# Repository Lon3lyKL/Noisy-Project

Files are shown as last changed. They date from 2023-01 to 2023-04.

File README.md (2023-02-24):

# Noisy-Project
This is a project by SSTudents for SSTudent to tell them to keep quiet during O Level Practical ;-;

Resources:
Check Resouces file

DATA:
- https://docs.google.com/spreadsheets/d/1UvS9qfeL-FOSvyElGNO4R17XsOqtYgqw1WRZXdFCIbs/edit#gid=698862983 
- cleaned up and formated with graph

27/1/23: Things to do
"use 741" -ms teo for speech pricessing
Kar Lok:
-   add a dc voltage regulator that can supply >3A current
    - we can use this 5v5A one https://www.amazon.sg/Pololu-Step-Down-Voltage-Regulator-D24V50F5/dp/B01M659ER2 
-   make the Rtc + SD card work
    - sd card formatting should be [dd/mm/yy_hh.mm.ss_data]
-  change the mega to a mini(save space) / mega
-  redesigning the lights
    - mounting of the leds
    - diffuser
    - distance to diffuser
-  add a fan into the control box to provide cooling to the components cos it gna run for 24/7

Jay:
-   try to do mic v2 and make it work with a condensor mic

3/2/23: Update
- we integrated the sd card and rtc
- we set up the recording structure into the sd card
- we set up the rtc to the exact time
- we found a few osciliscopes dead
- we found a few broken osciliscope probe
- we made the amplifier circuit to work
    - the mic we used is the wrong one
            - the pickup pattern is completely wrong
    - we used the lm741 ic to amplify it

what we need to do: 
- get a better mic
- go back on wed to collect the data
- pcb hehehawhaw

8/2/23: Update
- the data on monday was ok with us being able to see the points where students came down for thier breaks and there was noise recorded
- the tuesday data was weird it got all flipped and we have no clue what happened
- first time collecting the data it was good
- the sd card and the rtc works
- the google sheet was created with the correct formuls to create the graph to visualise the data

22/2/23: Update
- we got the data from 8-10 feb and it was ok, sensitivity of the mic has to be changed
    - at soome poitns the mic recoded 22 whcih was loud(we still have no clue what happened)
- changed the sampling rate to every 30 seconds form every 10 seconds
- changed the parameters for when the light will trigger for the dfferent volumes
    - 900> == quiet
    - 600> <900 == modertely noisy
    - <600 == very noisy
- tested it with some of us talking and got it to moderate noise
- realised the rtc was configured to be one day ahead(small problem, the date wont be used)
- planning to leave it until 24 feb(fri) even overnicet to collect the data
- fine tuning the number to be able to record a video of it for the principal
- shoudl be the last time we touched the code, nothing else needs to be changed
- 30s allows more data to be averaged out with the anomolies measured from electrical noise to be removed
- it will change the light less often thus the students will not stand there to watch it
- the green light on top of the mic can be used to check if the calibration of the gain is corrected
- changed the name of the project to "Noisy Student Project" from "Noisy Boi Project" to use more gender neutral terms
- (maybe we changed it before today im not sure) but ms teo was made aware of it today
- heard from other students it works sometimes when they tried to use it

things done: 
- acrylic top pannel was created
- tuned the mic to the correct sensitivity

things to improve: 
- add proper connectors for the rgb
- test the mic amps: jay
- test the rf moduled: karlok
- redesign led case: karlok
- redesign led mounting system: karlok (jay has some comments about this)

24/2/23: Update
- 22-23 feb data was very good
- we are able to see when the students are making noise
- the students breaks and end of school times were clearly visiable in the graph
- changed the limit when quiet to 800
- changed the limit when abit noisy to 550 and 800
- changed the limit when very noisy 550
- sensor will be placed at corridor between canteen and science lab
- sound sensor to be placed in science lab to record and corelate data
- v2 will have design improvements
- this mic is probably good enough and we wont need to get a different long range mic
- there was an error in the google sheets
    - taking the last 3 numbers willl miss out the times when the number is at 1020 and take it as 20
    - making it show up as anamoly
- changed to take the last 4 numbers

things to improve: 
- see 22feb comments
- led wire needs strain relief
- v2 to be done by next fri(3 mar)
- create a noise recorder for sci lab(sensor+sdcard)
- generally clean it up

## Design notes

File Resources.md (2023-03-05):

Resources:
- https://arduino-tutorials.net/tutorial/drawing-sound-sensor-data-on-serial-plotter sound sensor
- https://www.circuitbasics.com/how-to-use-a-real-time-clock-module-with-the-arduino/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,and%20Time%20on%20an%20Arduino. rtc
- https://randomnerdtutorials.com/guide-for-microphone-sound-sensor-with-arduino/ sound sensor
- https://www.instructables.com/Arduino-Audio-Input/ arduino audio input
- https://circuitdigest.com/microcontroller-projects/interfacing-ds3231-rtc-with-arduino-and-diy-digital-clock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,hour%20or%2012%2Dhour%20mode. arduino rtc how to use
- https://forum.arduino.cc/t/zs-042-ds3231-rtc-module/268862 notes about the rtc charging circuit
- https://digitalab.org/2016/08/microphone-pre-amplifier-using-lm358/#.Y_Y89exBwdH lm358 audio preamp
- https://digitalab.org/2012/10/audio-amplifier-using-lm386/#.Y_Y89exBwdF lm386 audio amp
- https://www.digikey.sg/en/products/detail/texas-instruments/LM358P/277042 lm358 datasheet
- https://www.ti.com/lit/ds/symlink/lm358.pdf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 lm358 datasheet again
- https://www.whitenoisestudio.com/how-to/cable-soldering-schematics/ xlr mic wiring digram
- https://bestengineeringprojects.com/microphone-amplifier-using-op-amp-741/ lm741 preamp
- https://bestengineeringprojects.com/dynamic-microphone-pre-amplifier-circuit/ dynamic mic preamp without ic
- http://www.learningaboutelectronics.com/Articles/Difference-amplifier-circuit.php lm741 preamp(didnt work)
- http://www.learningaboutelectronics.com/Articles/How-to-connect-a-LM741-op-amp-chip-to-a-circuit lm741 amp(didnt work again)
- https://www.got-it.ai/solutions/excel-chat/excel-tutorial/miscellaneous/copy-value-from-every-nth-row copying from every nth row excel
- https://spreadsheetpoint.com/apply-formula-to-entire-column-google-sheets/ apply formula to entire column (Cmd+D)
- https://spreadsheetpoint.com/how-to-insert-multiple-columns-in-google-sheets/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,of%2026%20at%20a%20time.&text=This%20happens%20because%2C%20by%20default,Sheets%20only%20displays%2026%20columns. add more columns (Cmd+A then insert columns)
- https://www.google.com/search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 long range mic search
- https://sg.rs-online.com/web/p/industrial-circular-connectors/1115761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 3 pin connecter used for rgb and mic
- https://lastminuteengineers.com/ds3231-rtc-arduino-tutorial/ another rtc 
- https://jaazz.me/2014/03/11/how-to-wire-an-unbalanced-microphone-to-a-balanced-xlr-input/ xlr input
- https://www.terralec.co.uk/CableConnectors.aspx xlr input

Others:
- https://www.convert-measurement-units.com/conversion-calculator.php?type=kapazitaet  unit conversion calculator to save time LMAO
- https://www.google.com/search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 lm741 amps (google search)

each Led Package draws 50mA of curent at 5v https://www.pololu.com/product/2547
we have 100 leds which means 50mA*100=5000mA=5A
the voltage regulator on the mega is a D24V5F5, which outputs at 5v at a max of 500mA https://forum.arduino.cc/t/replace-voltage-regulator-on-arduino-mega/402325/4 

Arduino & C++ extension can be added to vscode to use to write arduino
arduino can be programmed through vscode and not need to use the arduino app
guide of how to use it https://www.youtube.com/watch?v=WVZxK2MEbE4

github notes: https://stackoverflow.com/questions/30038999/differences-between-commit-commit-and-push-commit-and-sync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,them%20with%20your%20local%20repository%20%22 
In GitHub, the "commit" action saves your changes to the local repository, while the "push" action sends those changes to a remote repository. "Commit and push" combines these two actions into one, allowing you to save your changes locally and then push them to a remote repository with a single command.

"Commit and sync" is a similar concept, but it also pulls down any changes from the remote repository that have been made since your last commit. This allows you to keep your local repository up to date with the latest changes from other contributors.

Finally, "commit and create pull request" combines the commit and push actions with the creation of a new pull request. This allows you to propose your changes for review by other contributors to the project, and start a discussion about the changes you've made.

In summary, the differences between these options are:

"Commit": saves your changes to the local repository "Commit and push": saves your changes to the local repository and pushes them to the remote repository "Commit and sync": saves your changes to the local repository, pulls down any new changes from the remote repository, and merges them with your local repository "Commit and create pull request": saves your changes to the local repository, pushes them to the remote repository, and creates a new pull request for review.
- https://www.pagerduty.com/resources/learn/what-is-a-pull-request/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,with%20the%20main%20project%20repository. what pull requests are (tell others you are done and need a review of code)

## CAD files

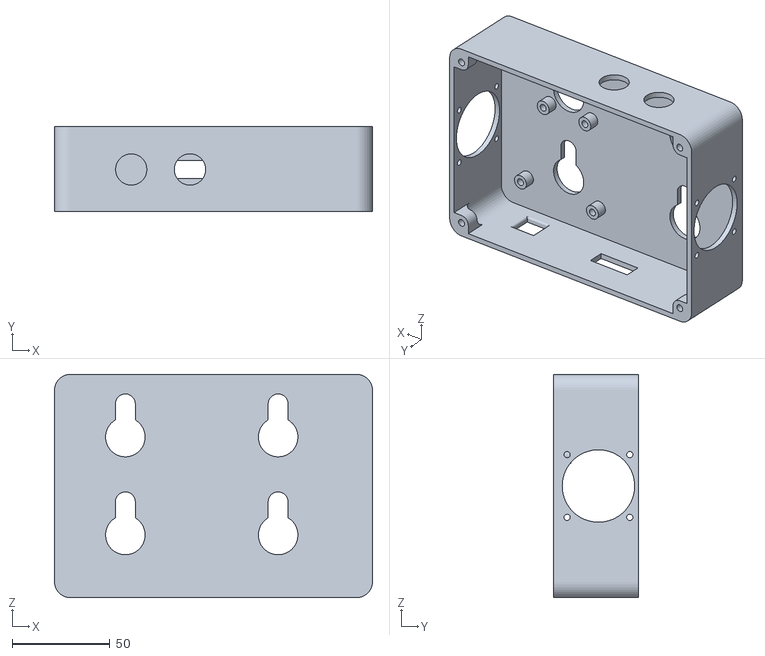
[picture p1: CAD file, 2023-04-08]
Noisy Project@SST/Contorl Box Model/Back Base V3.stl
162.3 x 43.5 x 114.0

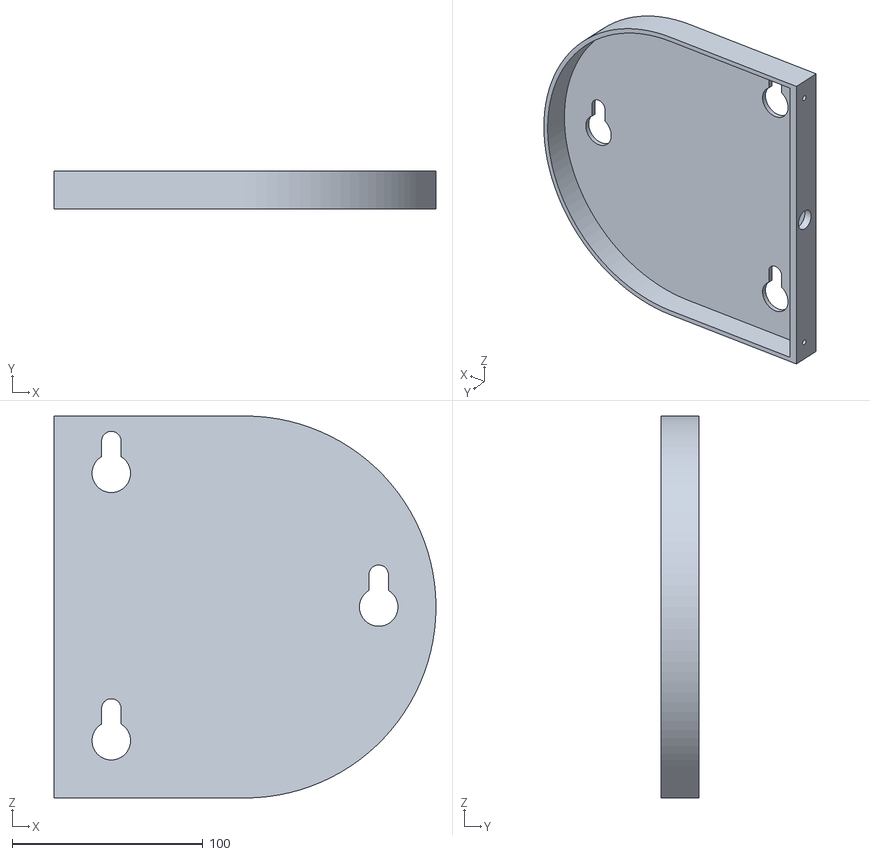
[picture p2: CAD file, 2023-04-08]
Noisy Project@SST/Light Model/Light Left.stl
200.0 x 20.0 x 200.0

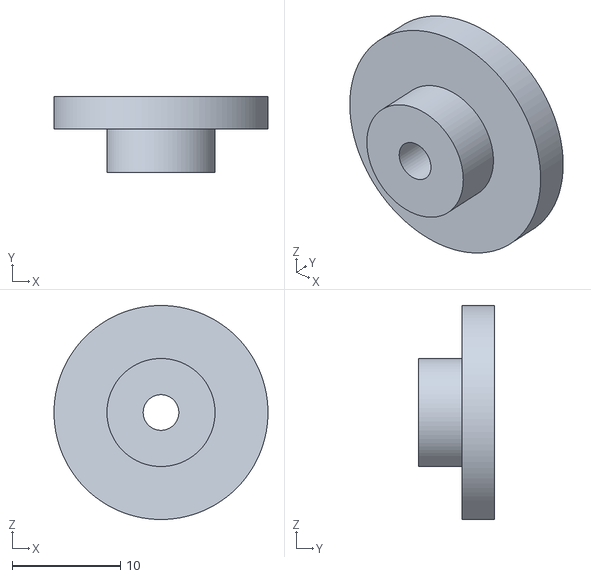
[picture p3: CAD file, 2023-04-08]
Noisy Project@SST/Mount.stl
19.8 x 7.00 x 19.8

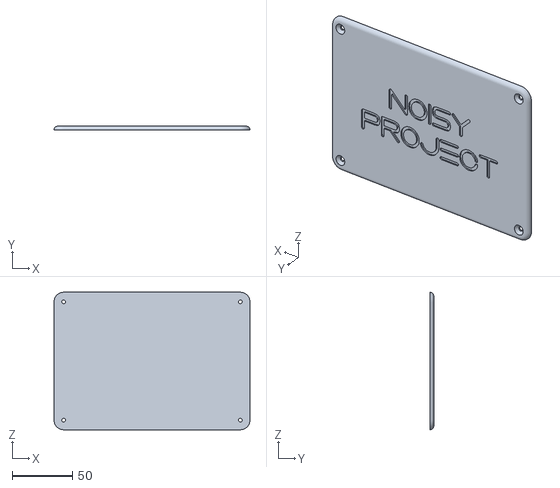
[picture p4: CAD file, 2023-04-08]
Noisy Project@SST/Contorl Box Model/Front Plate.stl
162.3 x 3.00 x 113.9

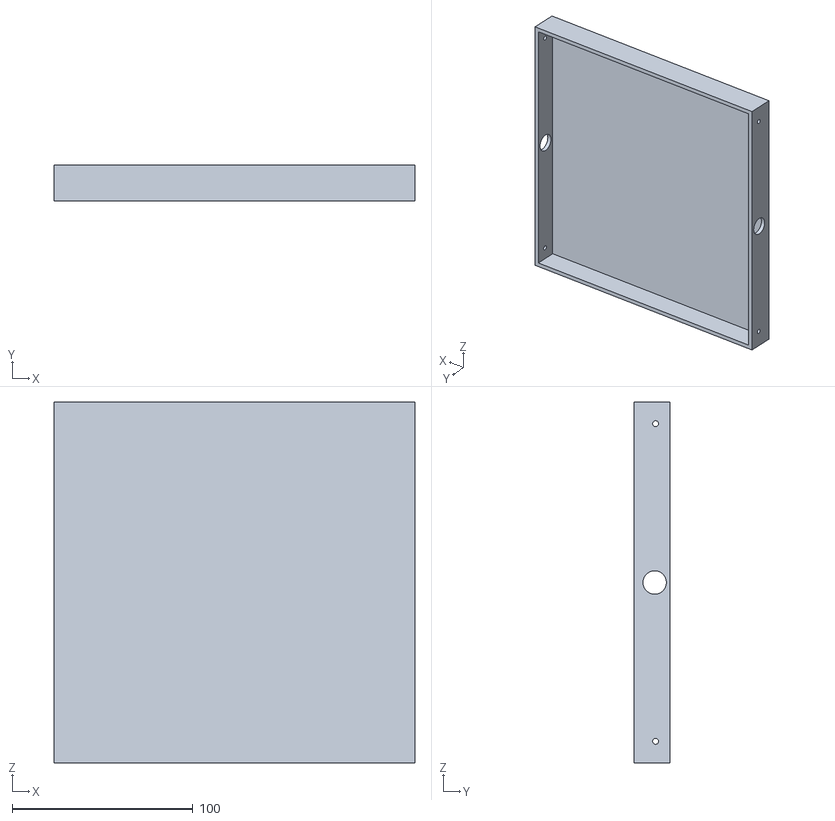
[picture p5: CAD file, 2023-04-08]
Noisy Project@SST/Light Model/Light Middle.stl
200.0 x 20.0 x 200.0

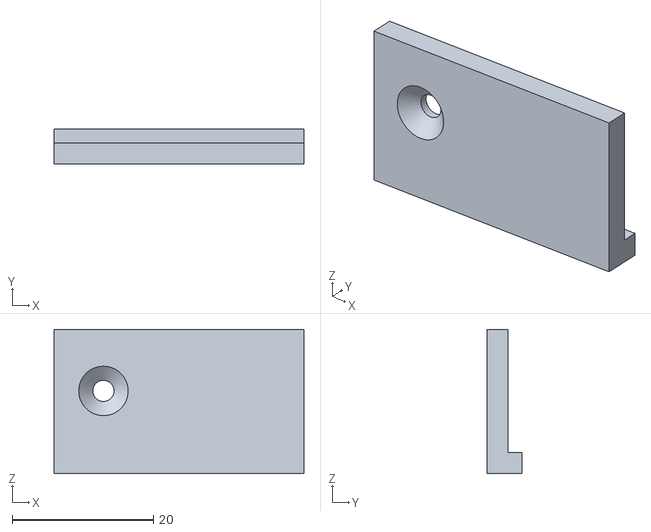
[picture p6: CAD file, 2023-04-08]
Noisy Project@SST/Mic Mount.stl
35.4 x 5.00 x 20.4

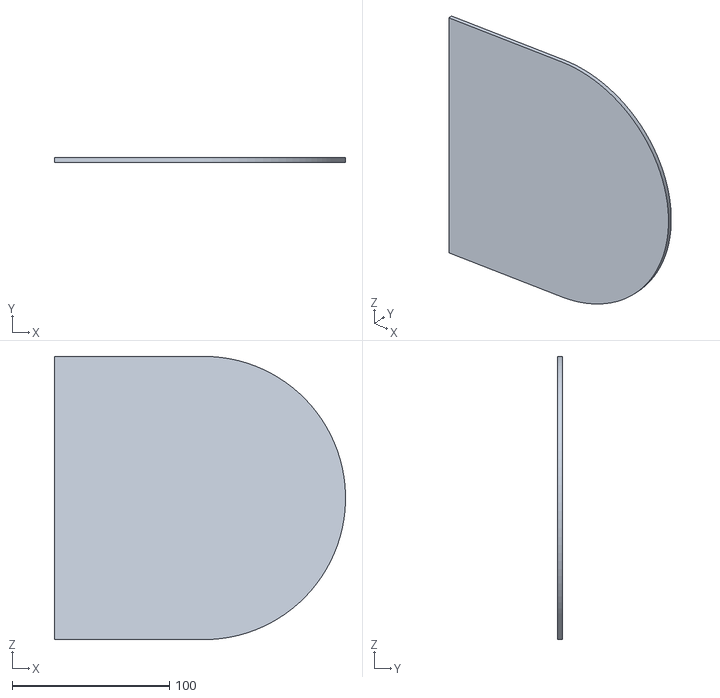
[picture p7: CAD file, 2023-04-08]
Noisy Project@SST/Light Model/Left_white.stl
185.0 x 3.00 x 180.0

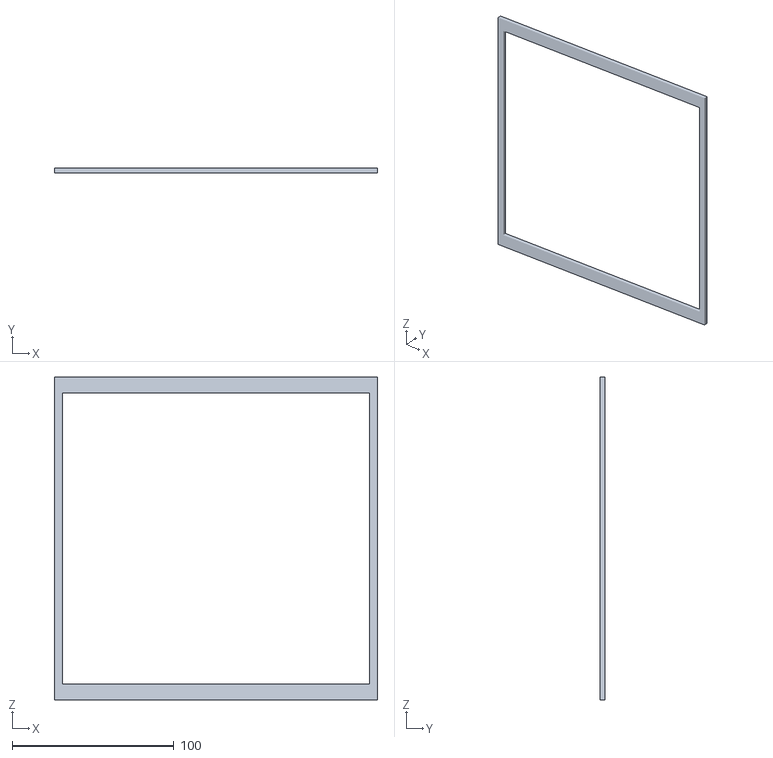
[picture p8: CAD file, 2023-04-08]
Noisy Project@SST/Light Model/Middle Cover.stl
200.0 x 3.00 x 200.0

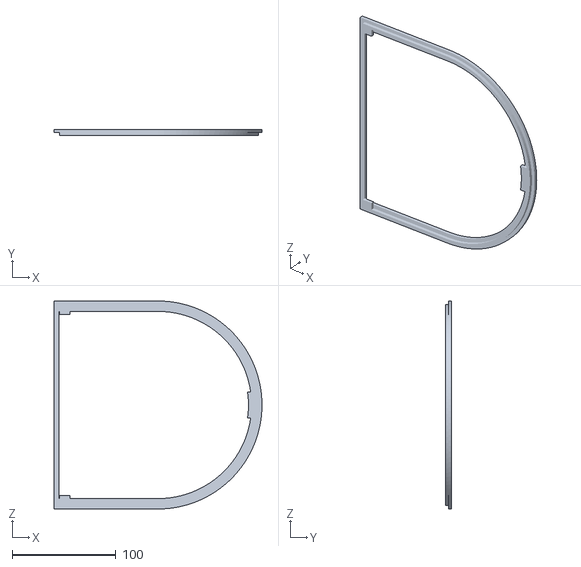
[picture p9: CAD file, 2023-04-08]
Noisy Project@SST/Light Model/Left Cover Updated.stl
200.0 x 6.00 x 200.0

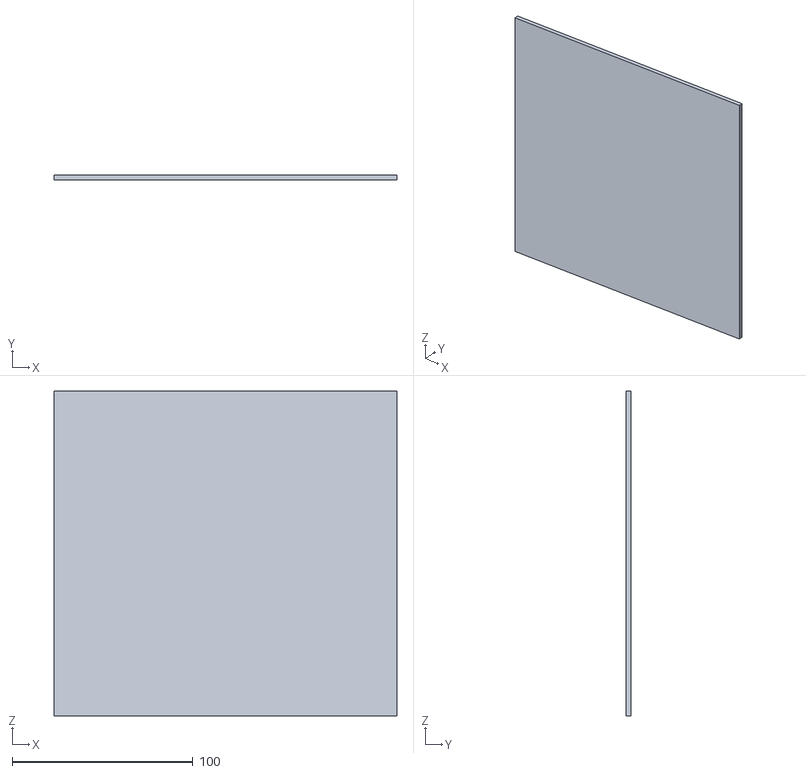
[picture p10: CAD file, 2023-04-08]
Noisy Project@SST/Light Model/Middle_white.stl
190.0 x 3.00 x 180.0

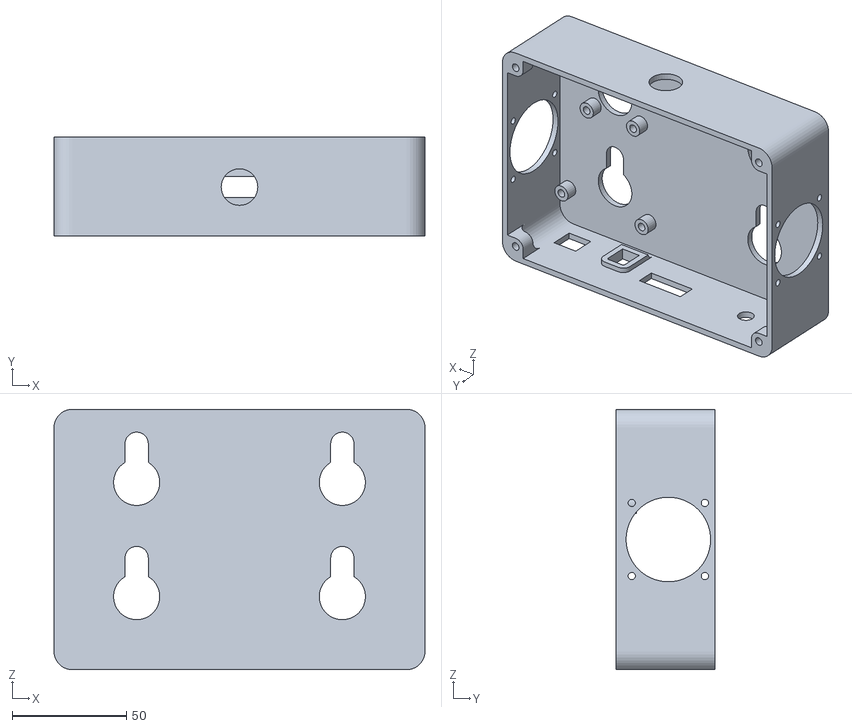
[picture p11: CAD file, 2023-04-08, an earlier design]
Noisy Project@SST/Contorl Box Model/Back Base V1.stl
162.3 x 43.5 x 114.0

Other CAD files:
Noisy Project@SST/Light Model/Light Right.stl
Noisy Project@SST/Light Model/Right Cover.stl
Noisy Project@SST/Light Model/Right_white.stl

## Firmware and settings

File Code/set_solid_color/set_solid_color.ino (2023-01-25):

#include <FastLED.h>
#define NUM_LEDS 10
#define DATA_PIN 8
CRGB leds[NUM_LEDS];
void setup() {
   	delay(2000);
    FastLED.addLeds<WS2812, DATA_PIN, GRB>(leds, NUM_LEDS);  // GRB ordering is typical
}

void loop() {
   for(int whiteLed = 0; whiteLed < NUM_LEDS; whiteLed = whiteLed + 1) {
      leds[whiteLed] = CRGB::Orange;
      FastLED.show();
      FastLED.setBrightness(  200 );
   }
}

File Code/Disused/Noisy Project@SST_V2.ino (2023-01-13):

//SD Card initialisation
#include <SPI.h>
#include <SD.h>
File myFile;

//Arduino Microphone initialisation
const int OUT_PIN = 8;
const int SAMPLE_TIME = 10;
unsigned long millisCurrent;
unsigned long millisLast = 0;
unsigned long millisElapsed = 0;
int sampleBufferValue = 0;


void setup(){ 
  Serial.begin(9600);
  while (!Serial) {
  ; // wait for serial port to connect. Needed for native USB port only
  }
  Serial.print("Initializing SD card...");
  if (!SD.begin(10)) {
  Serial.println("initialization failed!");
  while (1);
  }
  Serial.println("initialization done.");
  // open the file for reading:
  myFile = SD.open("test.txt");
  if (myFile) {
  Serial.println("test.txt:");
  // read from the file until there's nothing else in it:
  while (myFile.available()) {
  Serial.write(myFile.read());
  }
  // close the file:
  myFile.close();
  } else {
  // if the file didn't open, print an error:
  Serial.println("error opening test.txt");
  }
  }

void loop() {
  millisCurrent = millis();
  millisElapsed = millisCurrent - millisLast;

  if (digitalRead(OUT_PIN) == LOW) {
    sampleBufferValue++;
  }
 
  if (millisElapsed > SAMPLE_TIME) {
    Serial.println(sampleBufferValue);
    sampleBufferValue = 0;
    millisLast = millisCurrent;
    }
}

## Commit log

2023-01-27 cahnged the number of led initialised
2023-01-27 testing out using vscode to upload arduino code
2023-04-08 All STL models
    [Back Base V1.stl, Back Base V3.stl, Front Plate.stl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]
2023-06-01 fixed the rgb config for new rgb strip
    [Test_v4_all_works_with_3_different_lights.ino]
